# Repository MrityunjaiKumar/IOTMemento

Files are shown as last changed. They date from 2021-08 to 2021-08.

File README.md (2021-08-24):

# IOTMemento

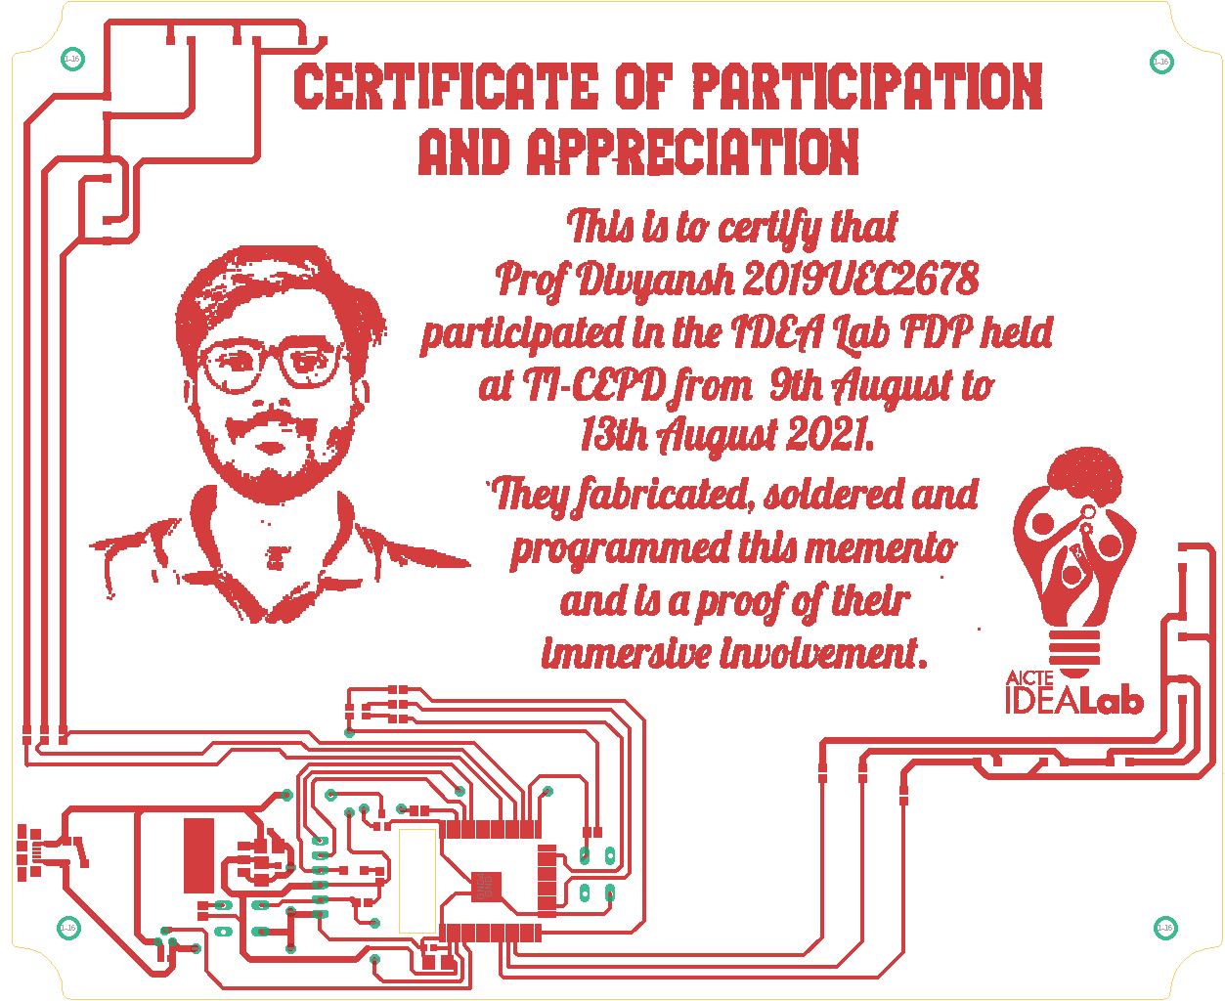
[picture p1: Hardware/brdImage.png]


## Introduction
This hardware was fabricated for AICTE Idea Lab FDP held at TI-CEPD, NSUT.
This repository is hosting tempalte code with Pinmapping and libraries information used during FDP. 
Also, An Android app is provided to view the data of the temperature form the hardware.
Features of this device are as follows:- 
1. Before wifi provisioning :- 

*  Rainbow pattern on RGB
*  Every 10 seconds all 12 petal leds will glow in linear fashion.

2. After wifi provisioning

* Rainbow pattern on RGB
* Play mario death tone every hour at 00 minute.
* Each of 12 petal leds will glow one after another in clockwise fashion, denoting complition of 5 minutes.
* Temperature sent to sincgrid cloud and data will be visible on sincgrid home app

### Design files

Editable files are located in Hardware folder

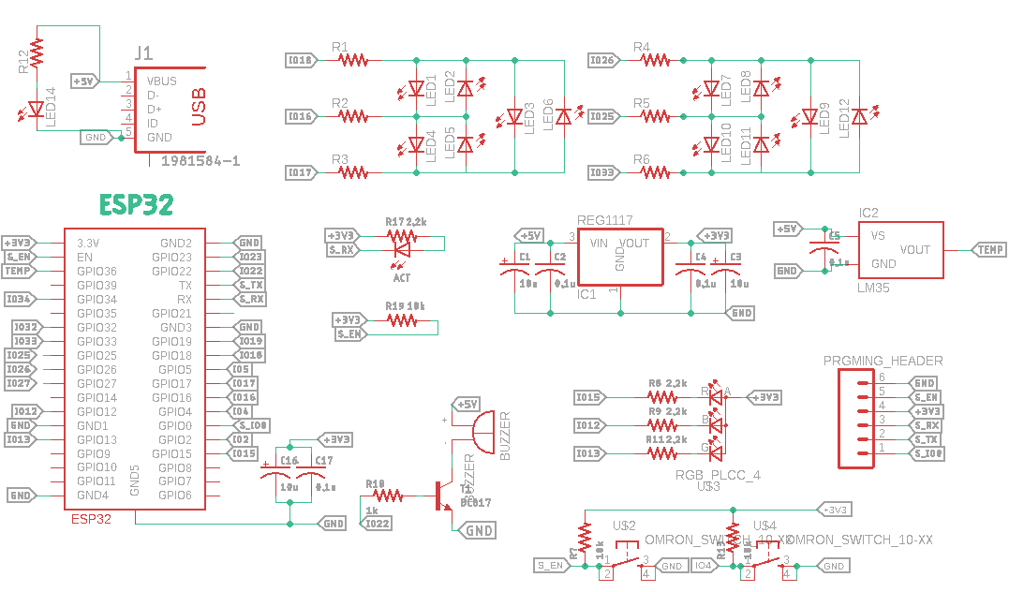
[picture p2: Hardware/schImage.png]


### Android APP
There is an Android application available at the play store for provisioning of the device (i.e. providing wifi ssid and passsword) and relaying the information.

Application can be located at https://play.google.com/store/apps/details?id=com.sincgrid.sincgridhome

Below are the steps needed to commision the device
1. Regsiter user
2. WiFi provision of the device
3. Regualr temperature update on the card

#### Registering the user
* After opening the app, Click on the Register button. 
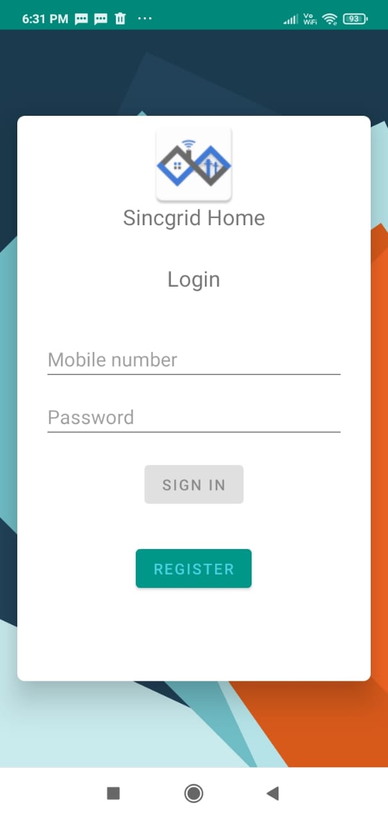
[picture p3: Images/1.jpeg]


* Fill in the details
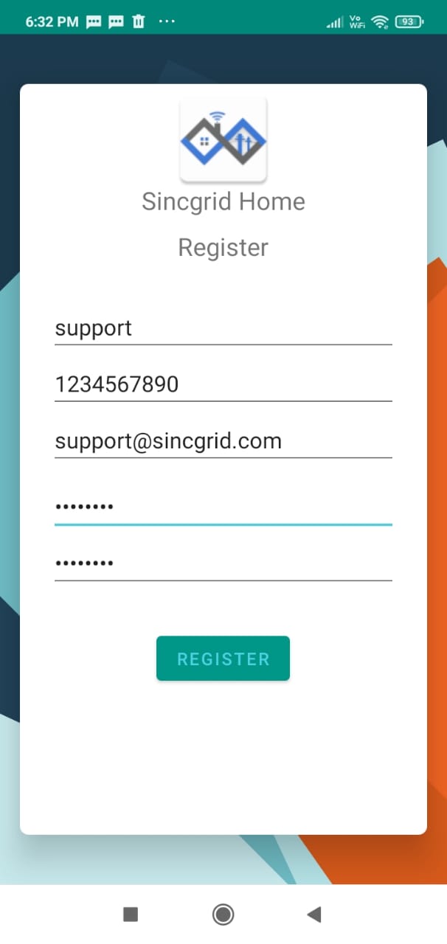
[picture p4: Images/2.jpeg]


* On provided email id, an OTP will be send. 
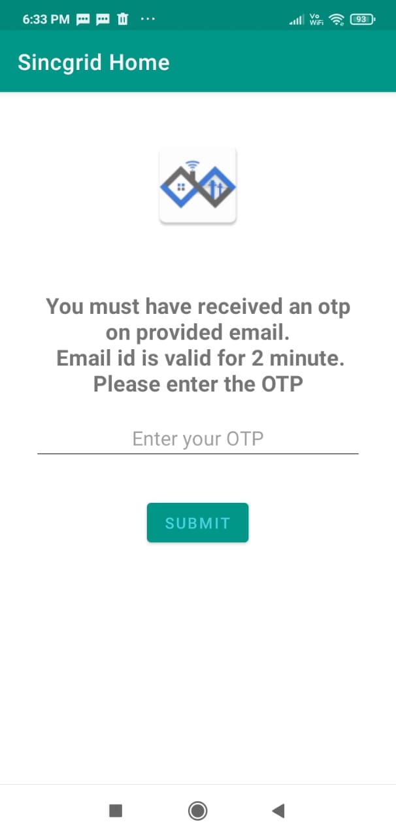
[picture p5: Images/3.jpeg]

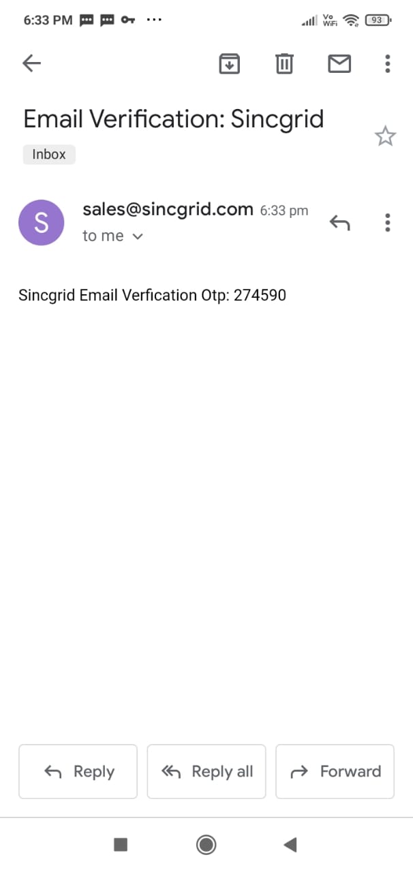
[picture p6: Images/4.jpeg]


* After confirming the OTP you will be logged in into the application.
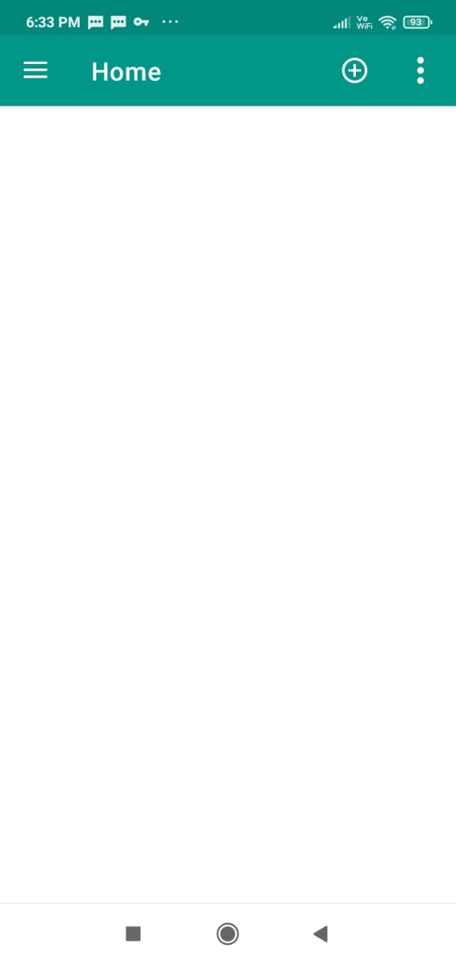
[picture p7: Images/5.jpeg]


#### WiFi provision of the device

* On App side Click on the add button to start provisioning

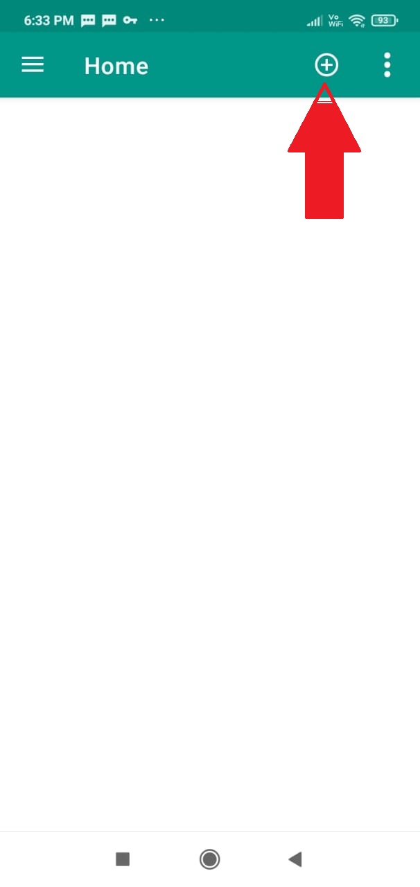
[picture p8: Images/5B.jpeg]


* On device side, Press the button for 5 second, you will hear a buzzer beep that mark as confirmation of initiation of provisioning.

* To whatever the wifi you phone is connected, that SSID will be taken by default. To change this, you can switch the wifi form the phone.

* Please provide the credentials of the the ssid.
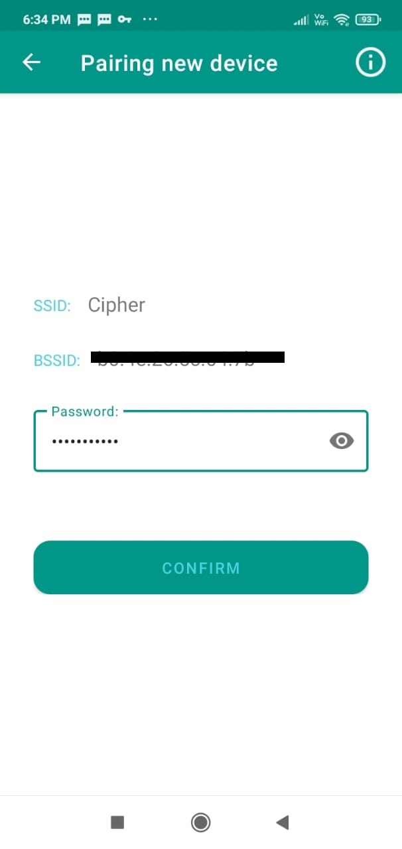
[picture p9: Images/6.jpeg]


After this app will automatically add the device.

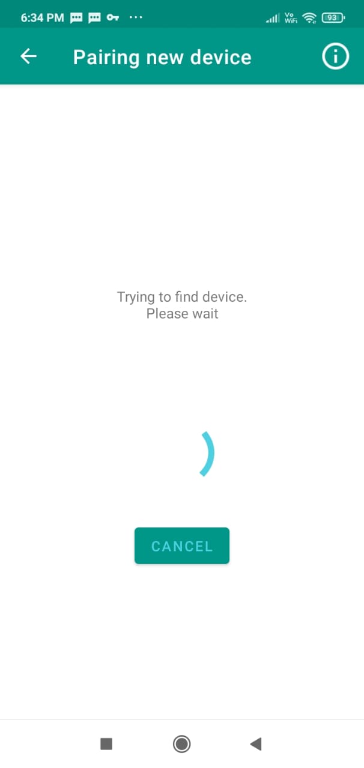
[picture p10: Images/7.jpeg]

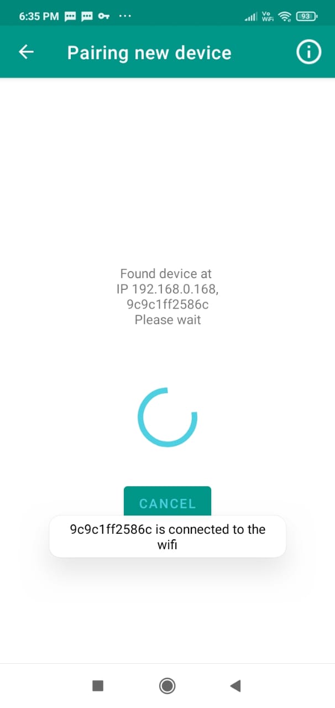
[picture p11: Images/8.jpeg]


#### Regualr temperature update on the card
After every 15 minutes device will send the temperature data from LM75.
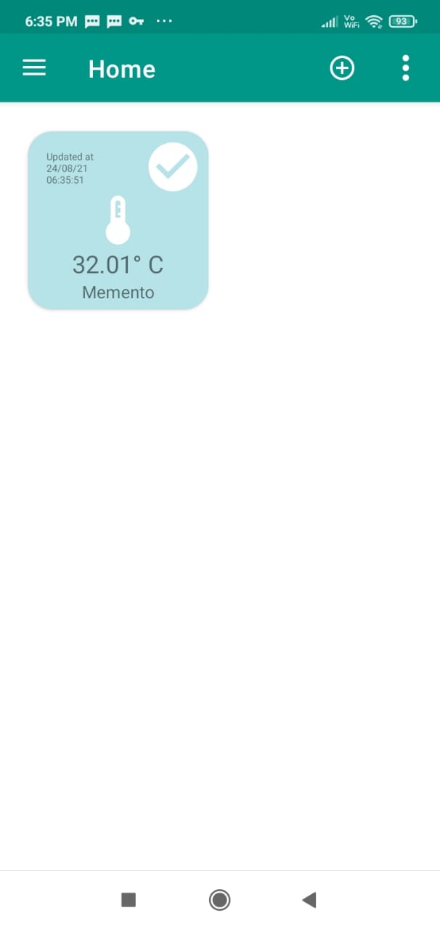
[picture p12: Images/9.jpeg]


## Libraries used during FDP are :- 

* [esp32-Encrypt](https://github.com/josephpal/esp32-Encrypt.git)
* bblanchon/ArduinoJson
* [ESPAsyncWebServer](https://github.com/me-no-dev/ESPAsyncWebServer.git)
* [AsyncTCP](https://github.com/me-no-dev/AsyncTCP.git)
* [ESP32_AnalogWrite](https://github.com/ERROPiX/ESP32_AnalogWrite.git)
* [NTPClient](https://github.com/MrityunjaiKumar/NTPClient.git)
* [Tone](https://github.com/lbernstone/Tone.git)
* PubSubClient

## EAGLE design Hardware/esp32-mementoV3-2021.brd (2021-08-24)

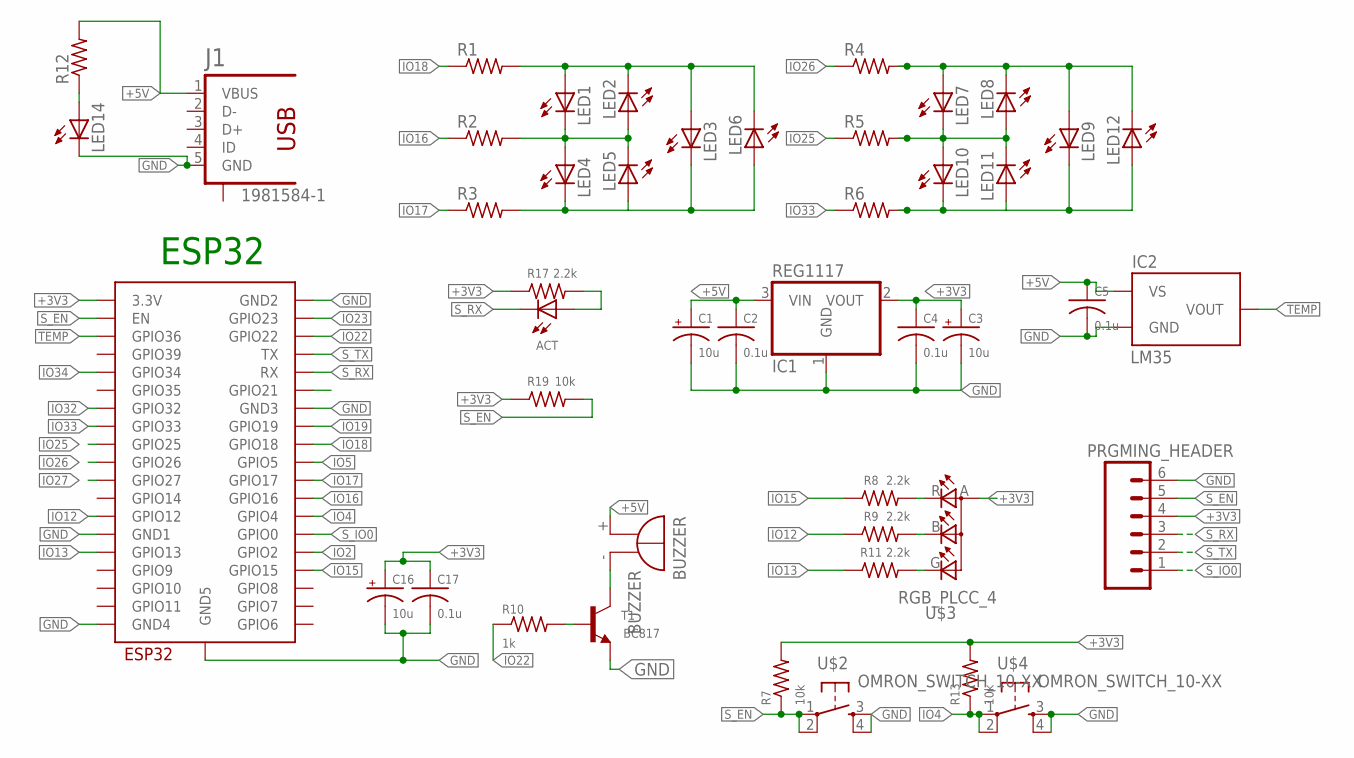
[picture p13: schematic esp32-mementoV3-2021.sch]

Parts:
ACT: LEDCHIPLED_1206; CHIPLED_1206
BUZZER: BUZZER; F/TMB
C1, C3, C16: 10u; B/3528-21R
C2, C4, C5, C17: 0.1u; C0603
ESP32_MODULE: ESP32-WROOM
IC1: REG1117; SOT223
IC2: LM35; TO92
J1: 1981584-1
LED1, LED2, LED3, LED4, LED5, LED6, LED7, LED8, LED9, LED10, LED11, LED12, LED14: LED1206; CHIPLED_1206
PRGMING_HEADER: M06; 06P
R1, R2, R3, R4, R5, R6, R12: RESISTOR0805; R0805
R7, R13: 10k; M0805
R8, R9, R11, R17: 2.2k; R0805
R10: 1k; M0805
R19: 10k; R0805
T1: BC817; SOT23-BEC
U$2, U$4: OMRON_SWITCH_10-XX; B3F-10XX
U$3: RGB_PLCC_4; PLCC-4

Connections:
+3V3: C3.+, C4.1, C16.+, C17.1, ESP32_MODULE.3V3 (3.3V), IC1.2 (VOUT), PRGMING_HEADER.4, R7.2, R13.2, R17.1, R19.1, U$3.A (A2)
+5V: BUZZER.+, C1.+, C2.1, C5.1, IC1.3 (VIN), IC2.VS, J1.1 (VBUS), R12.2
GND: C1.-, C2.2, C3.-, C4.2, C5.2, C16.-, C17.2, ESP32_MODULE.GND1, ESP32_MODULE.GND2, ESP32_MODULE.GND3, ESP32_MODULE.GND4, ESP32_MODULE.GND5, IC1.1 (GND), IC2.GND, J1.5 (GND), LED14.C, PRGMING_HEADER.6, T1.E, U$2.3 (S), U$2.4 (S1), U$4.3 (S), U$4.4 (S1)
IO2: ESP32_MODULE.IO2 (GPIO2)
IO4: ESP32_MODULE.IO4 (GPIO4), R13.1, U$4.1, U$4.2 (P1)
IO5: ESP32_MODULE.IO5 (GPIO5)
IO12: ESP32_MODULE.IO12 (GPIO12), R9.1
IO13: ESP32_MODULE.IO13 (GPIO13), R11.1
IO15: ESP32_MODULE.IO15 (GPIO15), R8.1
IO16: ESP32_MODULE.IO16 (GPIO16), R2.1
IO17: ESP32_MODULE.IO17 (GPIO17), R3.1
IO18: ESP32_MODULE.IO18 (GPIO18), R1.1
IO19: ESP32_MODULE.IO19 (GPIO19)
IO22: ESP32_MODULE.IO22 (GPIO22), R10.1
IO23: ESP32_MODULE.IO23 (GPIO23)
IO25: ESP32_MODULE.IO25 (GPIO25), R5.1
IO26: ESP32_MODULE.IO26 (GPIO26), R4.1
IO27: ESP32_MODULE.IO27 (GPIO27)
IO32: ESP32_MODULE.IO32 (GPIO32)
IO33: ESP32_MODULE.IO33 (GPIO33), R6.1
IO34: ESP32_MODULE.IO34 (GPIO34)
unnamed: LED1.A, LED2.C, LED3.A, LED6.C, R1.2
unnamed: LED1.C, LED2.A, LED4.A, LED5.C, R2.2
unnamed: LED3.C, LED4.C, LED5.A, LED6.A, R3.2
unnamed: LED7.A, LED8.C, LED9.A, LED12.C, R4.2
unnamed: LED7.C, LED8.A, LED10.A, LED11.C, R5.2
unnamed: LED9.C, LED10.C, LED11.A, LED12.A, R6.2
unnamed: BUZZER.-, T1.C
unnamed: R10.2, T1.B
unnamed: ACT.A, R17.2
unnamed: R8.2, U$3.R (CRED)
unnamed: R9.2, U$3.B (CBLUE)
unnamed: R11.2, U$3.G (CGREEN)
unnamed: LED14.A, R12.1
S_EN: ESP32_MODULE.EN, PRGMING_HEADER.5, R7.1, R19.2, U$2.1, U$2.2 (P1)
S_IO0: ESP32_MODULE.IO0 (GPIO0), PRGMING_HEADER.1
S_RX: ACT.C, ESP32_MODULE.RX, PRGMING_HEADER.3
S_TX: ESP32_MODULE.TX, PRGMING_HEADER.2
TEMP: ESP32_MODULE.SENSOR_VP (GPIO36), IC2.VOUT

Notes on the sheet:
ESP32

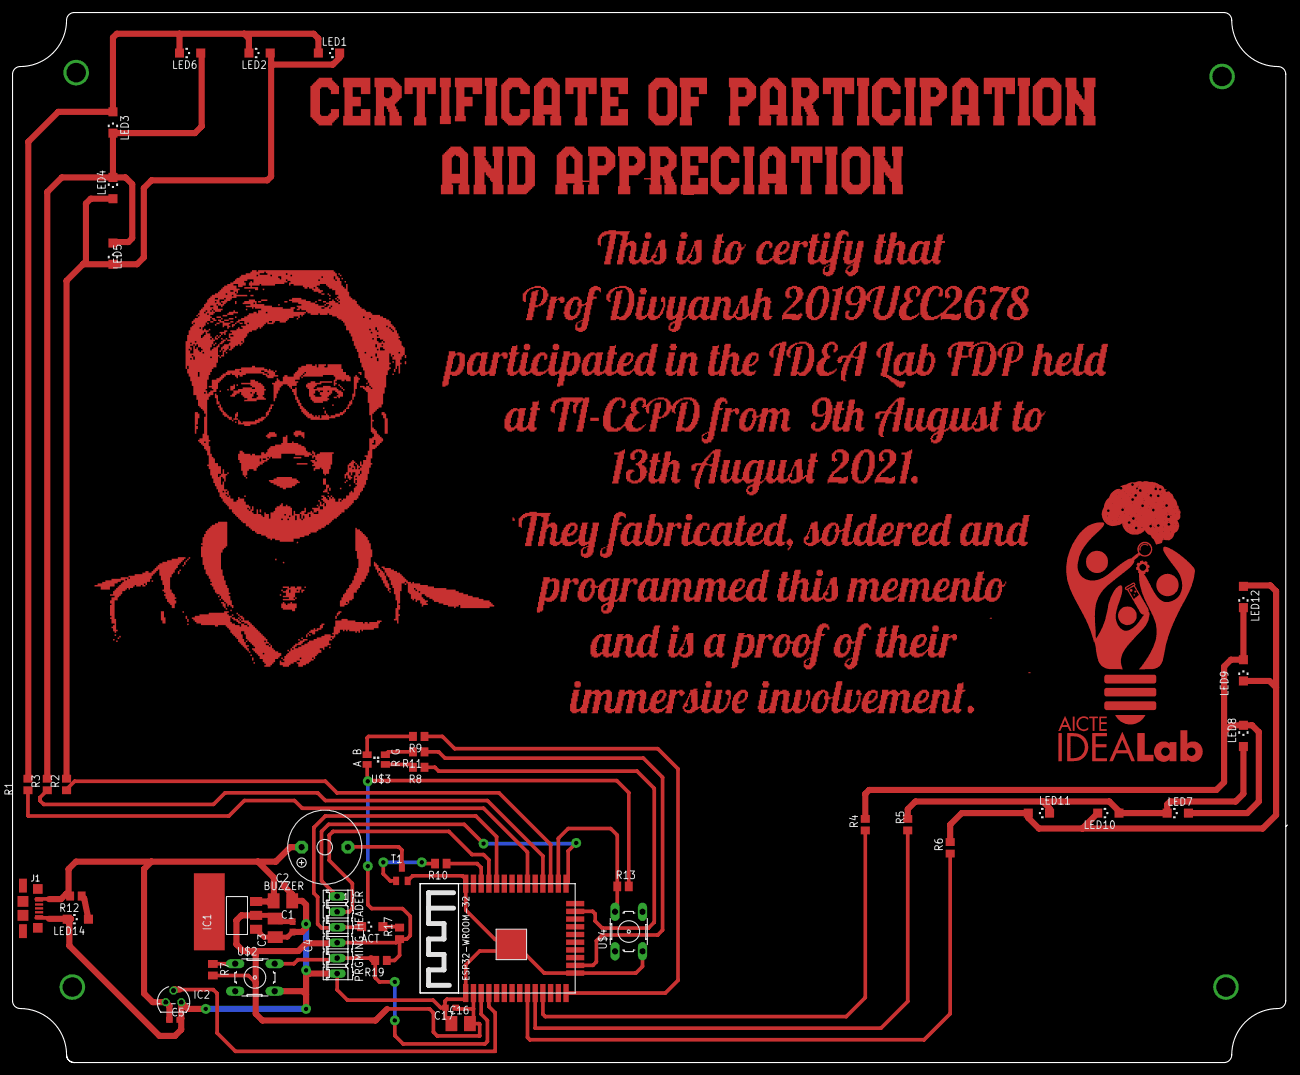
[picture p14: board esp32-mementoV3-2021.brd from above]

Board: 2 copper layers, 209.6 x 172.8 mm, 46 parts (0 on the bottom side), 32 nets.

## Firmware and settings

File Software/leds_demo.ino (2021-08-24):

const int p1 = 18, p2 = 16, p3 = 17, p4 = 26, p5 = 33, p6 = 25;
const int r_pin = 15, g_pin = 12, b_pin = 13;
const int buzzer = 22;
uint32_t timer = millis();
void setup() {
  pinMode(buzzer,OUTPUT);
}

void loop() {
  
  // case 1 -- six led bari bari
  // sub1

  digitalWrite(r_pin, LOW);
  pinMode(g_pin, INPUT);
  pinMode(b_pin, INPUT);
  
  pinMode(p1, INPUT);
  pinMode(p2, OUTPUT);
  pinMode(p3, OUTPUT);
  digitalWrite(p2, LOW);
  digitalWrite(p3, HIGH);

  pinMode(p4, INPUT);
  pinMode(p5, OUTPUT);
  pinMode(p6, OUTPUT);
  digitalWrite(p5, LOW);
  digitalWrite(p6, HIGH);
  
  digitalWrite(buzzer, HIGH);
  delay(250);
  digitalWrite(buzzer, LOW);
  delay(250);

  digitalWrite(p3, LOW);
  digitalWrite(p6, LOW);
  delay(500);

  //sub2
  pinMode(p1, INPUT);
  pinMode(p2, OUTPUT);
  pinMode(p3, OUTPUT);
  digitalWrite(p2, HIGH);
  digitalWrite(p3, LOW);

  pinMode(p4, INPUT);
  pinMode(p5, OUTPUT);
  pinMode(p6, OUTPUT);
  digitalWrite(p5, HIGH);
  digitalWrite(p6, LOW);
  
  digitalWrite(buzzer, HIGH);
  delay(250);
  digitalWrite(buzzer, LOW);
  delay(250);

  digitalWrite(p2, LOW);
  digitalWrite(p5, LOW);
  delay(500);

  //sub3
  pinMode(p2, INPUT);
  pinMode(p1, OUTPUT);
  pinMode(p3, OUTPUT);
  digitalWrite(p1, HIGH);
  digitalWrite(p3, LOW);

  pinMode(p6, INPUT);
  pinMode(p5, OUTPUT);
  pinMode(p4, OUTPUT);
  digitalWrite(p5, LOW);
  digitalWrite(p4, HIGH);
  
  digitalWrite(buzzer, HIGH);
  delay(250);
  digitalWrite(buzzer, LOW);
  delay(250);

  digitalWrite(p1, LOW);
  digitalWrite(p4, LOW);
  delay(500);

  //sub4
  pinMode(p2, INPUT);
  pinMode(p1, OUTPUT);
  pinMode(p3, OUTPUT);
  digitalWrite(p1, LOW);
  digitalWrite(p3, HIGH);

  pinMode(p6, INPUT);
  pinMode(p5, OUTPUT);
  pinMode(p4, OUTPUT);
  digitalWrite(p4, LOW);
  digitalWrite(p5, HIGH);
  
  digitalWrite(buzzer, HIGH);
  delay(250);
  digitalWrite(buzzer, LOW);
  delay(250);

  digitalWrite(p3, LOW);
  digitalWrite(p5, LOW);
  delay(500);

  //sub5
  pinMode(p3, INPUT);
  pinMode(p2, OUTPUT);
  pinMode(p1, OUTPUT);
  digitalWrite(p1, LOW);
  digitalWrite(p2, HIGH);

  pinMode(p5, INPUT);
  pinMode(p4, OUTPUT);
  pinMode(p6, OUTPUT);
  digitalWrite(p4, HIGH);
  digitalWrite(p6, LOW);
  
  digitalWrite(buzzer, HIGH);
  delay(250);
  digitalWrite(buzzer, LOW);
  delay(250);

  digitalWrite(p2, LOW);
  digitalWrite(p4, LOW);
  delay(500);

  //sub6
  pinMode(p3, INPUT);
  pinMode(p2, OUTPUT);
  pinMode(p1, OUTPUT);
  digitalWrite(p2, LOW);
  digitalWrite(p1, HIGH);

  pinMode(p5, INPUT);
  pinMode(p4, OUTPUT);
  pinMode(p6, OUTPUT);
  digitalWrite(p4, LOW);
  digitalWrite(p6, HIGH);
  
  digitalWrite(buzzer, HIGH);
  delay(250);
  digitalWrite(buzzer, LOW);
  delay(250);

  digitalWrite(p1, LOW);
  digitalWrite(p6, LOW);
  delay(500);


  // CASE 2 --- all led ek sath

  for(int i = 0; i<2; i++)
  {
      if(i==0)
      {
        digitalWrite(g_pin, LOW);
        pinMode(r_pin, INPUT);
        pinMode(b_pin, INPUT);
      }
      else{
        digitalWrite(b_pin, LOW);
        pinMode(g_pin, INPUT);
        pinMode(r_pin, INPUT);
      }
      timer = millis();
      while(millis() - timer < 1000)
      {  
        pinMode(p1, INPUT);
        pinMode(p2, OUTPUT);
        pinMode(p3, OUTPUT);
        digitalWrite(p2, LOW);
        digitalWrite(p3, HIGH);
      
        pinMode(p4, INPUT);
        pinMode(p5, OUTPUT);
        pinMode(p6, OUTPUT);
        digitalWrite(p5, LOW);
        digitalWrite(p6, HIGH);
        
      
        delay(5);
      
        //sub2
        pinMode(p1, INPUT);
        pinMode(p2, OUTPUT);
        pinMode(p3, OUTPUT);
        digitalWrite(p2, HIGH);
        digitalWrite(p3, LOW);
      
        pinMode(p4, INPUT);
        pinMode(p5, OUTPUT);
        pinMode(p6, OUTPUT);
        digitalWrite(p5, HIGH);
        digitalWrite(p6, LOW);
       
        delay(5);
      
        //sub3
        pinMode(p2, INPUT);
        pinMode(p1, OUTPUT);
        pinMode(p3, OUTPUT);
        digitalWrite(p1, HIGH);
        digitalWrite(p3, LOW);
      
        pinMode(p6, INPUT);
        pinMode(p5, OUTPUT);
        pinMode(p4, OUTPUT);
        digitalWrite(p5, LOW);
        digitalWrite(p4, HIGH);
        
        delay(5);
      
        //sub4
        pinMode(p2, INPUT);
        pinMode(p1, OUTPUT);
        pinMode(p3, OUTPUT);
        digitalWrite(p1, LOW);
        digitalWrite(p3, HIGH);
      
        pinMode(p6, INPUT);
        pinMode(p5, OUTPUT);
        pinMode(p4, OUTPUT);
        digitalWrite(p4, LOW);
        digitalWrite(p5, HIGH);
      
        delay(5);
      
        //sub5
        pinMode(p3, INPUT);
        pinMode(p2, OUTPUT);
        pinMode(p1, OUTPUT);
        digitalWrite(p1, LOW);
        digitalWrite(p2, HIGH);
      
        pinMode(p5, INPUT);
        pinMode(p4, OUTPUT);
        pinMode(p6, OUTPUT);
        digitalWrite(p4, HIGH);
        digitalWrite(p6, LOW);
        
     
        delay(5);
      
        //sub6
        pinMode(p3, INPUT);
        pinMode(p2, OUTPUT);
        pinMode(p1, OUTPUT);
        digitalWrite(p2, LOW);
        digitalWrite(p1, HIGH);
      
        pinMode(p5, INPUT);
        pinMode(p4, OUTPUT);
        pinMode(p6, OUTPUT);
        digitalWrite(p4, LOW);
        digitalWrite(p6, HIGH);
      
        delay(5);
      }
      pinMode(p1, INPUT);
      pinMode(p2, INPUT);
      pinMode(p3, INPUT);
      pinMode(p4, INPUT);
      pinMode(p5, INPUT);
      pinMode(p6, INPUT);
      
      digitalWrite(buzzer, HIGH);
      delay(500);
      digitalWrite(buzzer, LOW);
  }
  
  
  
}

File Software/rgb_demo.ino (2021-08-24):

const int r_pin = 15, g_pin = 12, b_pin = 13,temp = 36;
void setup() {
  // put your setup code here, to run once:
pinMode(r_pin,OUTPUT);
pinMode(g_pin,OUTPUT);
pinMode(b_pin,OUTPUT);
pinMode(temp,INPUT);
Serial.begin(115200);
}

void loop() {
  // put your main code here, to run repeatedly:
Serial.println(analogRead(temp));
digitalWrite(r_pin,HIGH);
digitalWrite(b_pin,HIGH);
digitalWrite(g_pin,HIGH);

digitalWrite(r_pin,LOW);
delay(250);
digitalWrite(r_pin,HIGH);
delay(250);

digitalWrite(g_pin,LOW);
delay(250);
digitalWrite(g_pin,HIGH);
delay(250);

digitalWrite(b_pin,LOW);
delay(250);
digitalWrite(b_pin,HIGH);
delay(250);

}
